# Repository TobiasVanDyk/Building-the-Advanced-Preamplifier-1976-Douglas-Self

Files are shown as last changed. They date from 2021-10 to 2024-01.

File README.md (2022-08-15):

**Copyright 1976 November Wireless World An Advanced Preamplifier** by [**Douglas Self**](http://www.douglas-self.com/ampins/library/ampartew.htm)

Douglas Self's audio design books are also recommended on Github: [**How to learn modern electronics**](https://github.com/joaocarvalhoopen/How_to_learn_modern_electronics)

This is the most musically sounding preamp I have built. The photograph shows the two normalization and tone control PCB's constructed in the middle 1980's, re-housed in a recent (partially) 3d-printed, case. The input level control is at the back of the case. 

<p align="left">
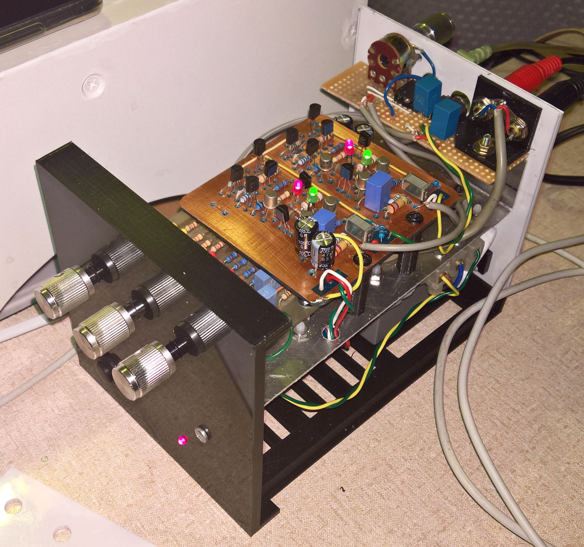
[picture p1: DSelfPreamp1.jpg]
  
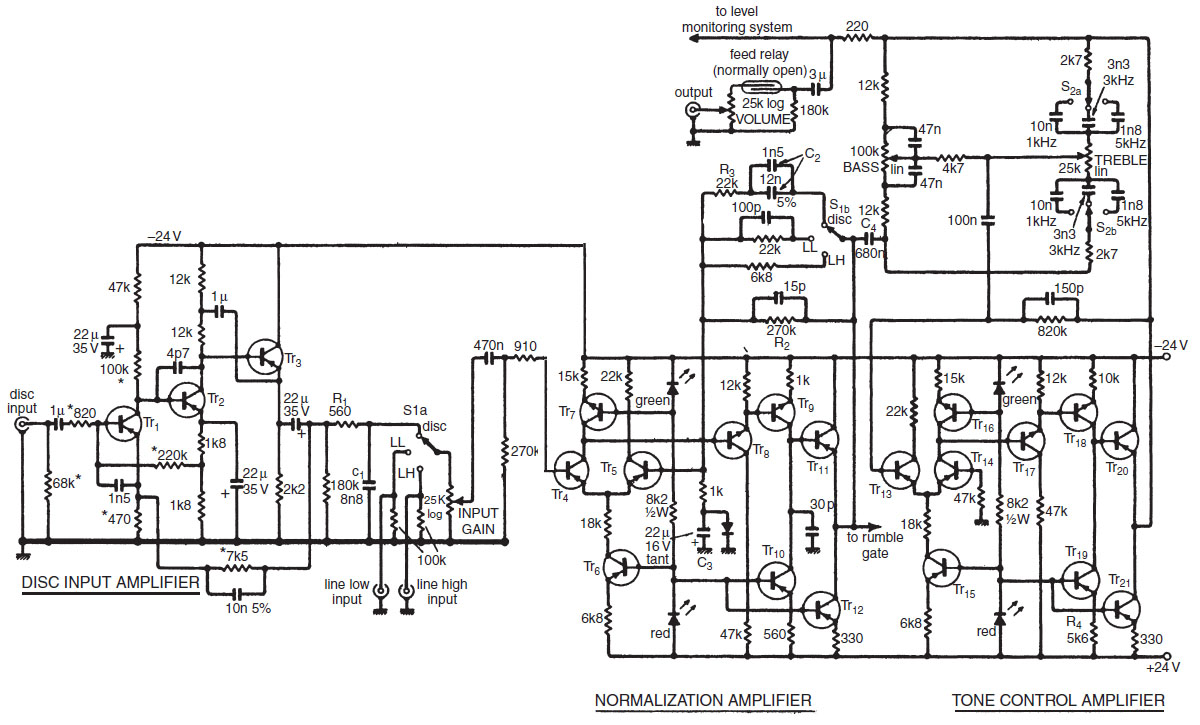
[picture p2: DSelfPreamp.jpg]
   
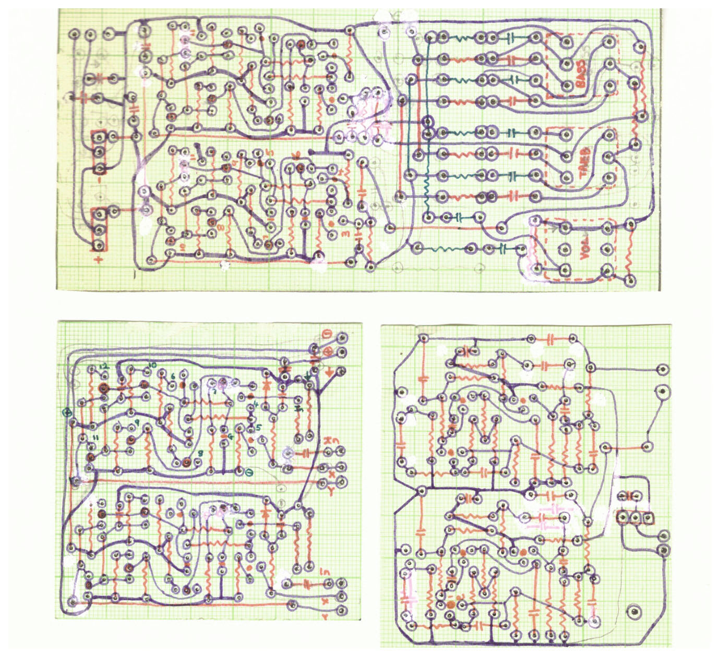
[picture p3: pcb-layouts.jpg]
  	
</p>
	
Listening during the past year (2020/2021) to this preamp driving a linear-PSU-powered class-D-amp prompted the construction of a second preamp - the unpopulated PCBs have been made and the components obtained. More details are in the [AdvPreAmp2021Build](AdvPreAmp2021Build) folder including the Fritzing PCB layout files. (*No, it is not cool to have to create a schematic, if all that you want is a PCB based on a perfectly good schematic that you already have. [Note 1](https://github.com/geedotk/CS42448_T4_TEST2) [Note 2](https://hackaday.io/project/2984-teensy-audio-library/log/187557-updated-cs42448-pcb-for-teensy-4x)*) An old trick that I use to make the PCB photomasks is to laserprint on normal white paper, rub some sunflower oil over the non-toner side, and then let it dry for 24 hours.

<p align="left">
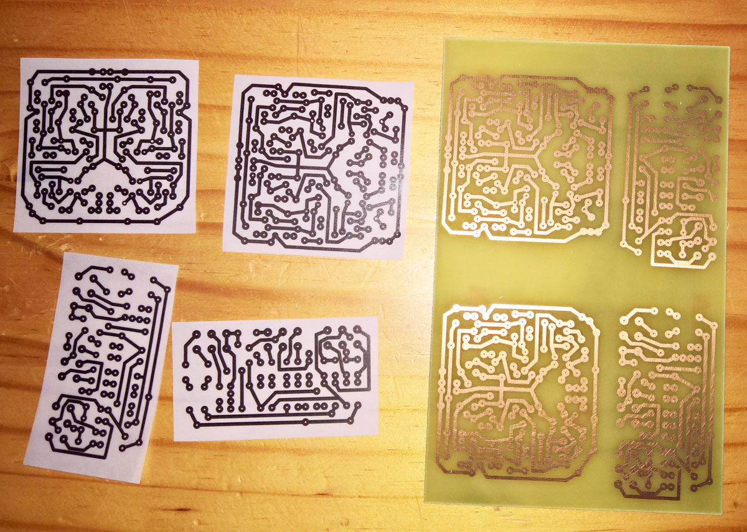
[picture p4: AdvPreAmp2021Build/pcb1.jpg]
  
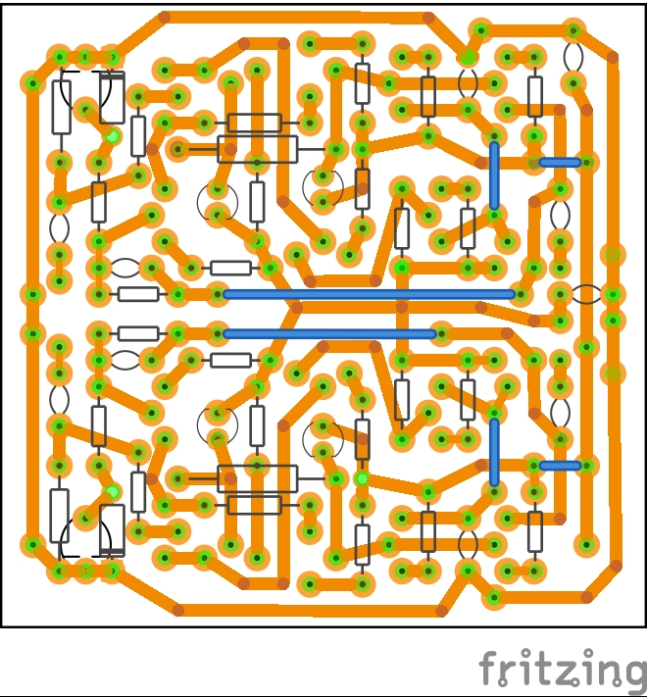
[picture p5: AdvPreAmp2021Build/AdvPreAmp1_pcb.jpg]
   
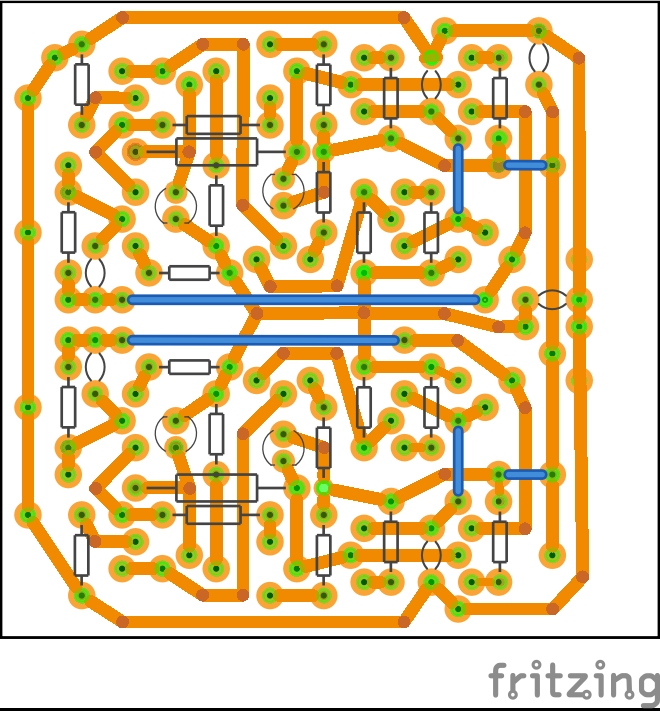
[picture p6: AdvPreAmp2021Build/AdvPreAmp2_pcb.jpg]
  
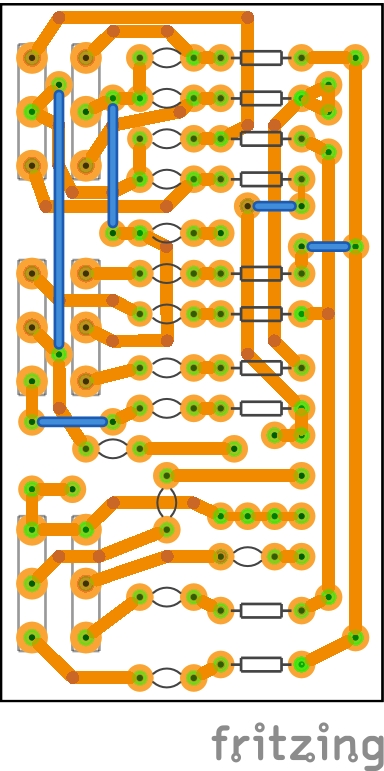
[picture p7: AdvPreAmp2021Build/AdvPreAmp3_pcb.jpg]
  
</p>

The Preamp electronics have been completed - only the case is left to make or print:
<p align="left">
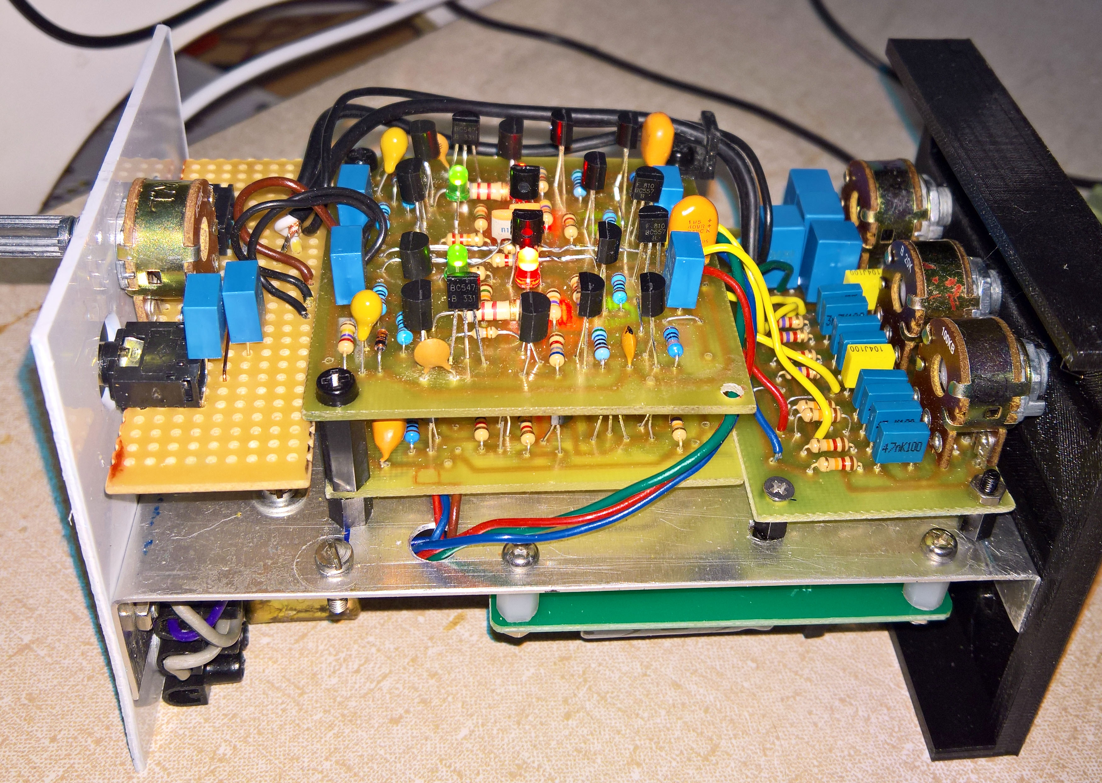
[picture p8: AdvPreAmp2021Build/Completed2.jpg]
  
</p>

This turned out to be almost half the size of the 1980's based preamp, and puzzlingly it has a distinctly different sound (but neither better nor worse), than the older preamp.

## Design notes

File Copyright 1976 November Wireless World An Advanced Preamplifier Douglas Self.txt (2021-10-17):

Copyright 1976 November Wireless World An Advanced Preamplifier Douglas Self

http://www.douglas-self.com/ampins/library/ampartew.htm

This is the most musically sounding preamp I have ever built. The photograph shows the two normalization and tone control PCB's from the middle 1980's re-housed in a recent case.

<p align="left">
  
    
</p>

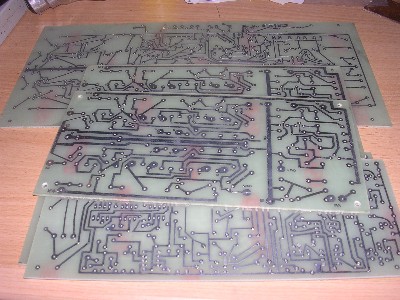
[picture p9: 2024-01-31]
original-pcb.jpg

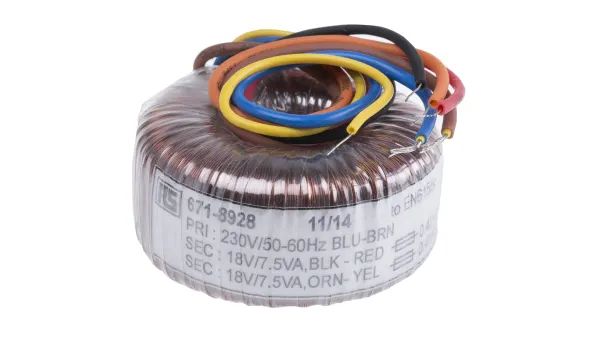
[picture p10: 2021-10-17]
RSPro-671-8928.jpg

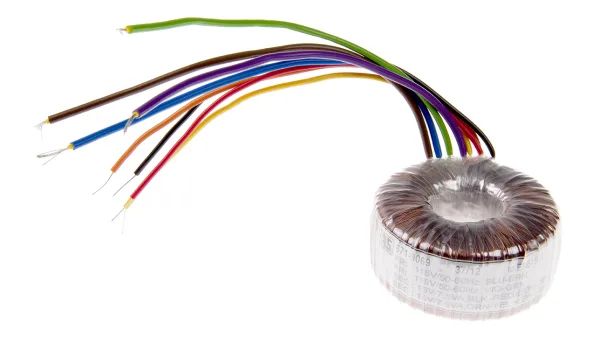
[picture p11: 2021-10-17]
RSPro-671-9069.jpg

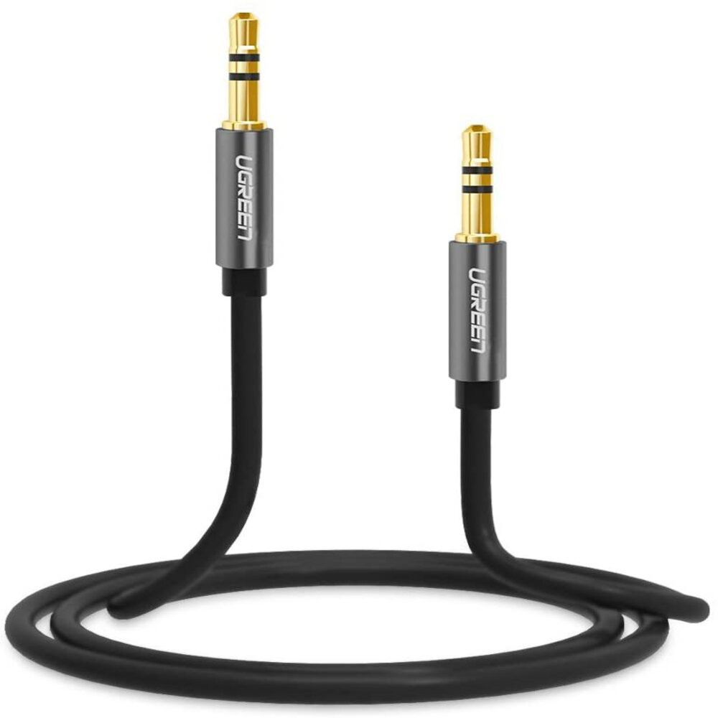
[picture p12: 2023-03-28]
AudioSwitchBox-3Way/UGreen 3mm5 50cm Audio Cable.jpg

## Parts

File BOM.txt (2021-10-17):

BOM: Normalization Amp and Tone Control Amp only
------------------------------------------------
Tr4  5  6  13 14 15  are BCY71  PNP
Tr7  8  9  16 17 18  are MPSA06 NPN
Tr10 11 12 19 20 21  are MPSA56 PNP
MPSA56 x 12
MPSA06 x 12
BCY71 (BC560C) x 12
Note: 
1. MPSA06 and MPSA56 are still manufactured
MPSA56 https://www.mantech.co.za/ProductInfo.aspx?Item=14M6921
MPSA06 https://www.mantech.co.za/ProductInfo.aspx?Item=14M6920
2. BCY71 can be substituted with BC560C
BC560C https://www.mantech.co.za/ProductInfo.aspx?Item=14M0390
3. For Disc Imput Amp add BCY71 (BC560C) x 6 
   And resistors/capacitors as per circuit diagram
--------------------------------------------------------
220 x 2
330 x 4
560 x 2
910 x 2
1k x 8
2k7 x 4
4k7 x 2
5k6 x 2
6k8 x 6
8k2 x 4 1/2 W
10k x 4
12k x 8
15k x 4
18k x 4
22k x 6
47k x 4
100k x 4
180k x 2
270k x 4
820k x 2
-----------------
25k dual log x 2
25k dual lin x 1
100k dual lin x 1
-----------------
15pF x 2
30pF x 2
100pF x 2
150pF x 2
10n x 4
3n3 x 4
1n8 x 4
47n x 4
100n x 2
470n x 2
3uF x 2
22uF 16v electrolytic x 2
--------------------------
PSU:
18-0-18 volt 15VA toroidal transformwr RSPro 671-8928 https://za.rs-online.com/web/p/toroidal-transformers/6718928/ (1985 re-build)
15-0-15 volt 15VA toroidal transformwr RSPro-671-9069 https://za.rs-online.com/web/p/toroidal-transformers/6719069/ (2021 new build)
4700uF 35v x 2 
400v 2A bridge rectifier

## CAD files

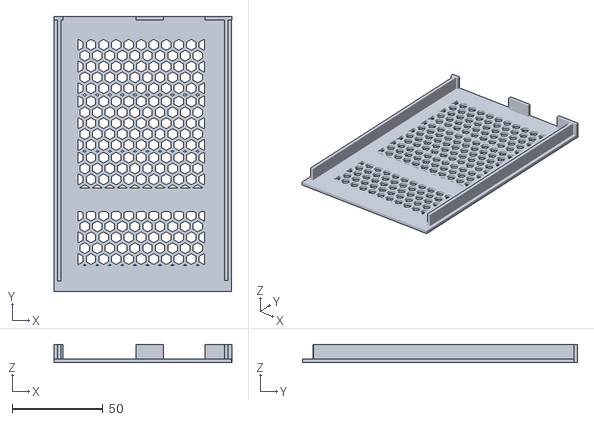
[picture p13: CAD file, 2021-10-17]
1985buildSTL/1985Top.stl
98.3 x 152.0 x 10.0

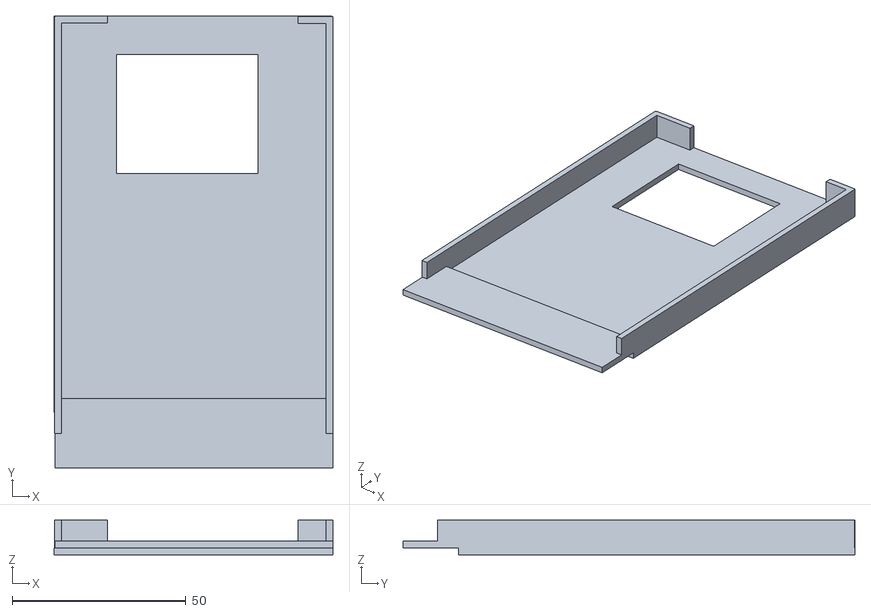
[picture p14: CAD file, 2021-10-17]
AdvPreAmp2021Build/2021buildSTL/2021Bottom.stl
80.3 x 130.2 x 10.0

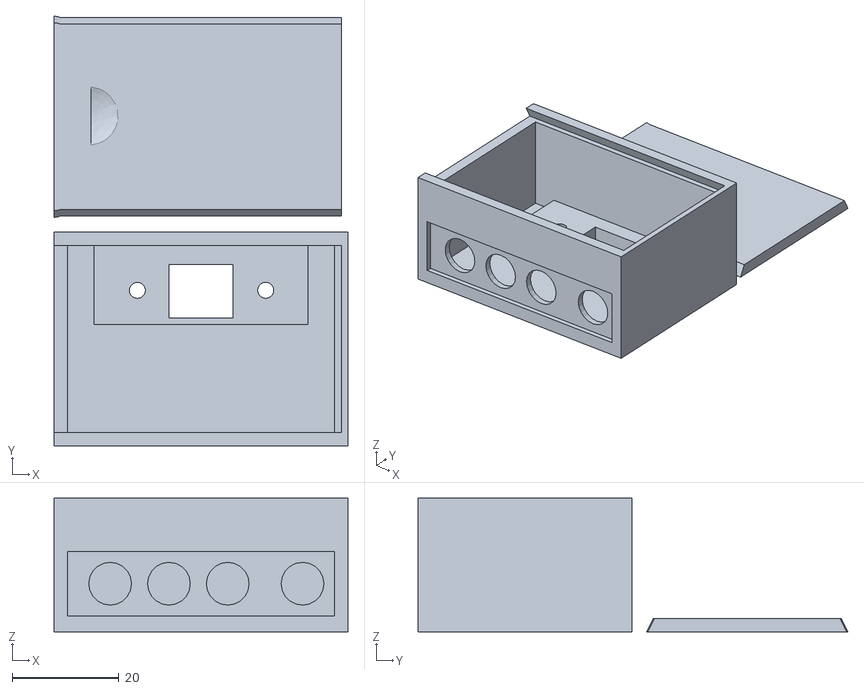
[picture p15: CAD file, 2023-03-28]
AudioSwitchBox-3Way/AudioSwitchBox5.stl
55.0 x 80.4 x 25.0

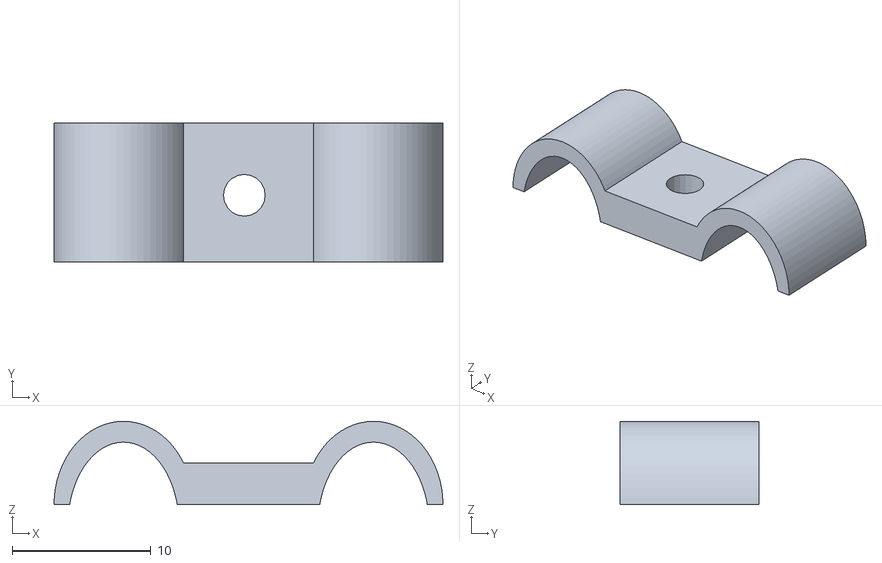
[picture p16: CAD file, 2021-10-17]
1985buildSTL/DoubleClamp.stl
28.0 x 10.0 x 6.00

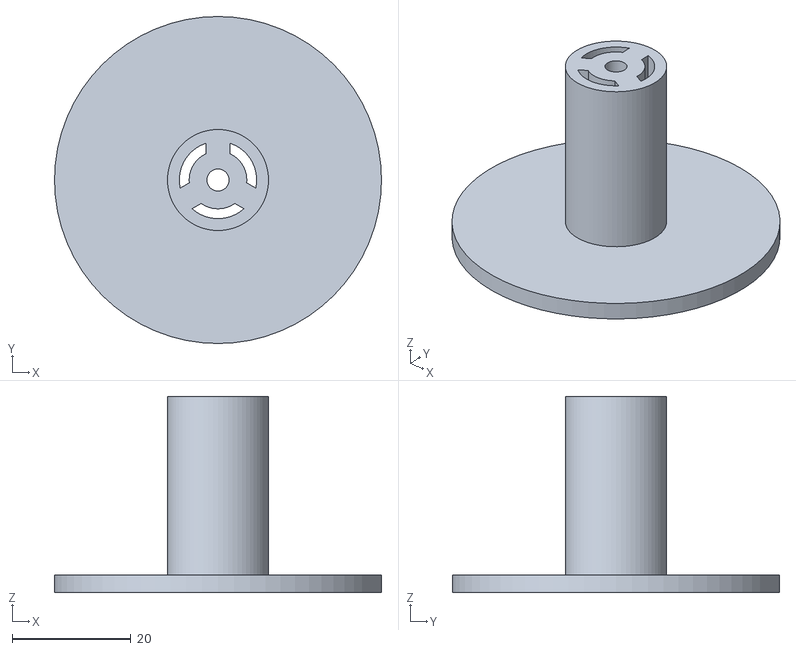
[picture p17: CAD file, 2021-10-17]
AdvPreAmp2021Build/2021buildSTL/Transformer Toroidal 15VA 2x18V.stl
55.0 x 55.0 x 33.0

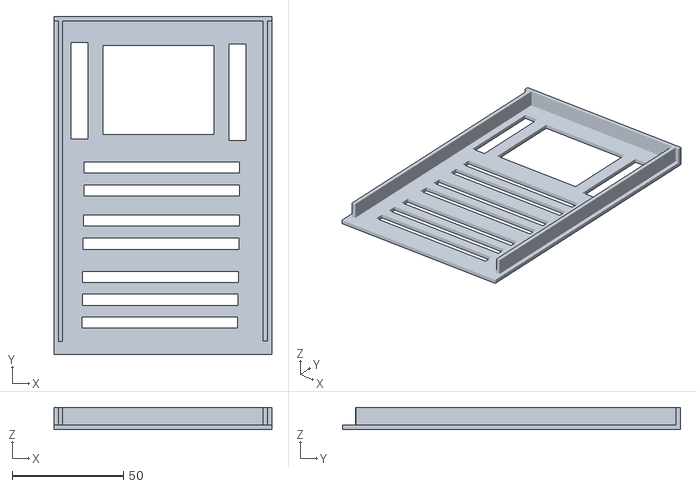
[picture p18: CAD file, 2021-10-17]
1985buildSTL/1985Bottom.stl
98.0 x 152.0 x 10.0

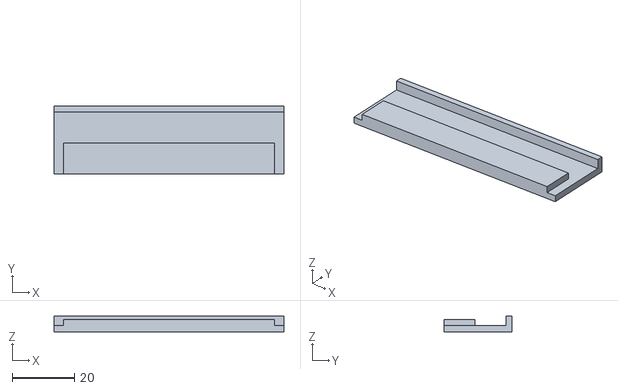
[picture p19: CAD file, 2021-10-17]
AdvPreAmp2021Build/2021buildSTL/2021TopPartB.stl
74.0 x 22.0 x 5.00

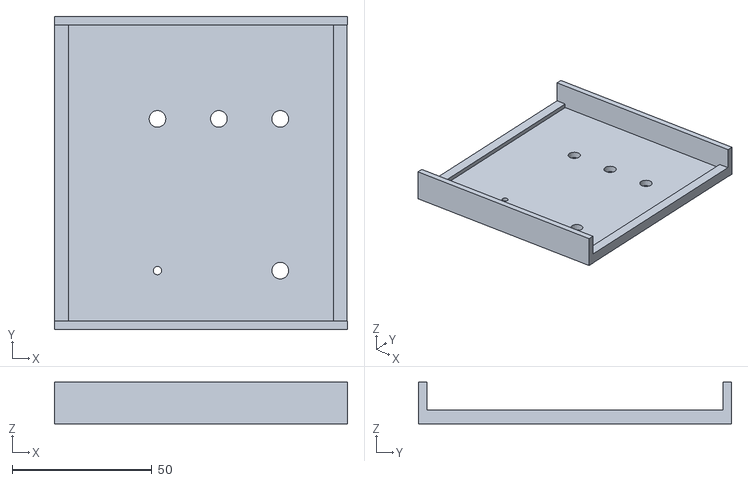
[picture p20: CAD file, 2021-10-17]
1985buildSTL/1985Front.stl
105.0 x 112.2 x 15.0

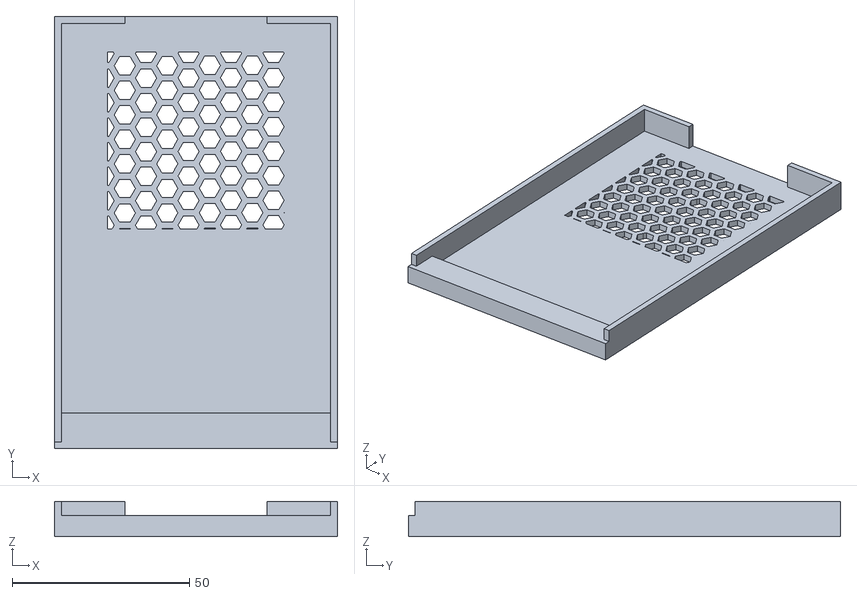
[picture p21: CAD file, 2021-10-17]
AdvPreAmp2021Build/2021buildSTL/2021TopPartA.stl
80.0 x 122.0 x 10.0

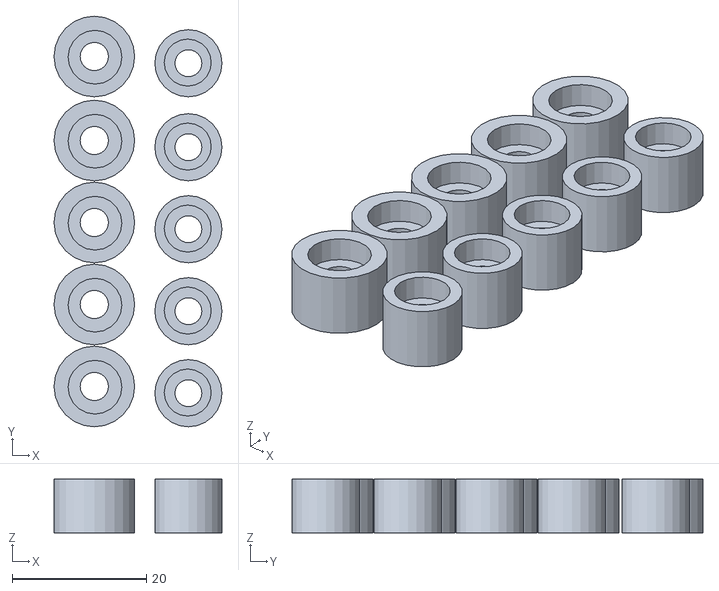
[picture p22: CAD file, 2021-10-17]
AdvPreAmp2021Build/2021buildSTL/2021CaseFeet1.stl
25.0 x 61.1 x 8.00

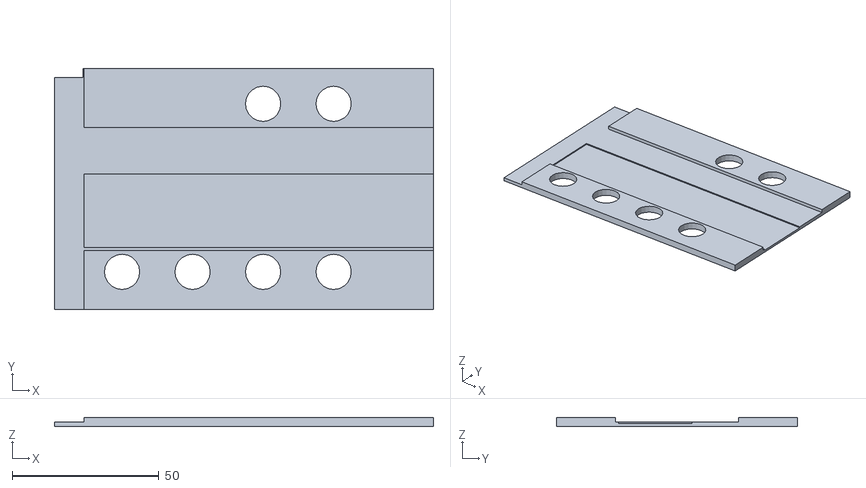
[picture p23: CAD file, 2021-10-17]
AdvPreAmp2021Build/2021buildSTL/PreampSideR.stl
129.0 x 82.0 x 3.00

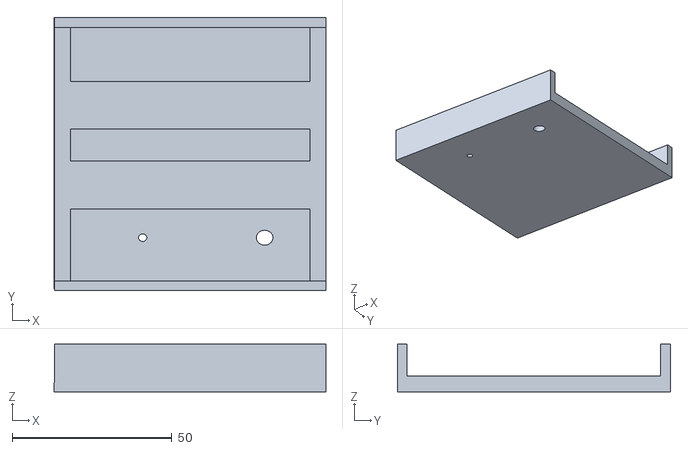
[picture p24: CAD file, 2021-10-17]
AdvPreAmp2021Build/2021buildSTL/2021Front.stl
85.1 x 85.5 x 15.0

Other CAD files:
AdvPreAmp2021Build/2021buildSTL/PreampSideL.stl

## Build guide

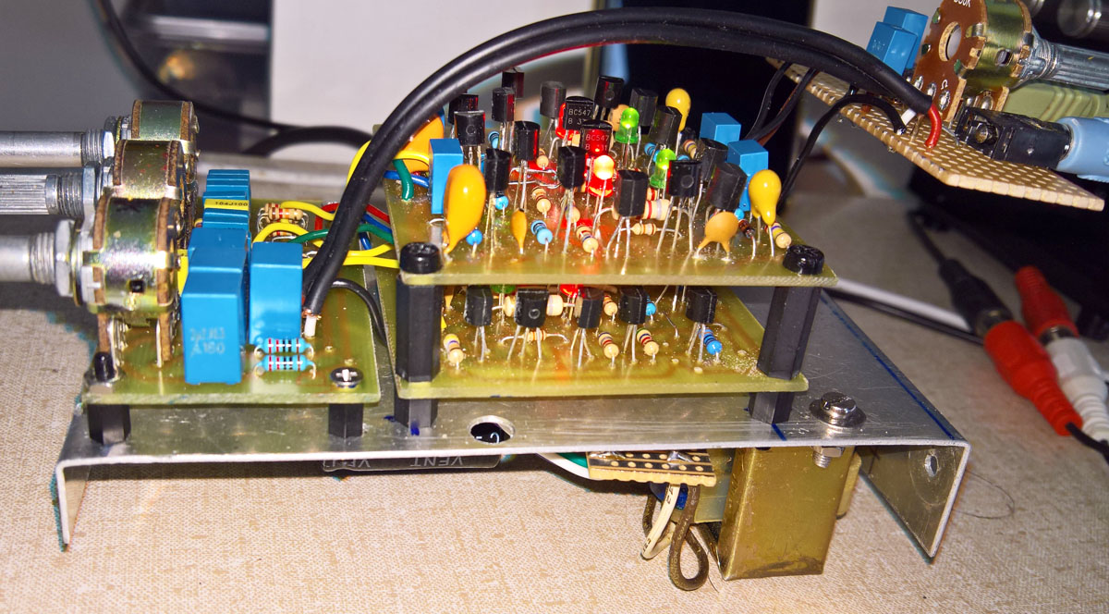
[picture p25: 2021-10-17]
AdvPreAmp2021Build/Completed1.jpg

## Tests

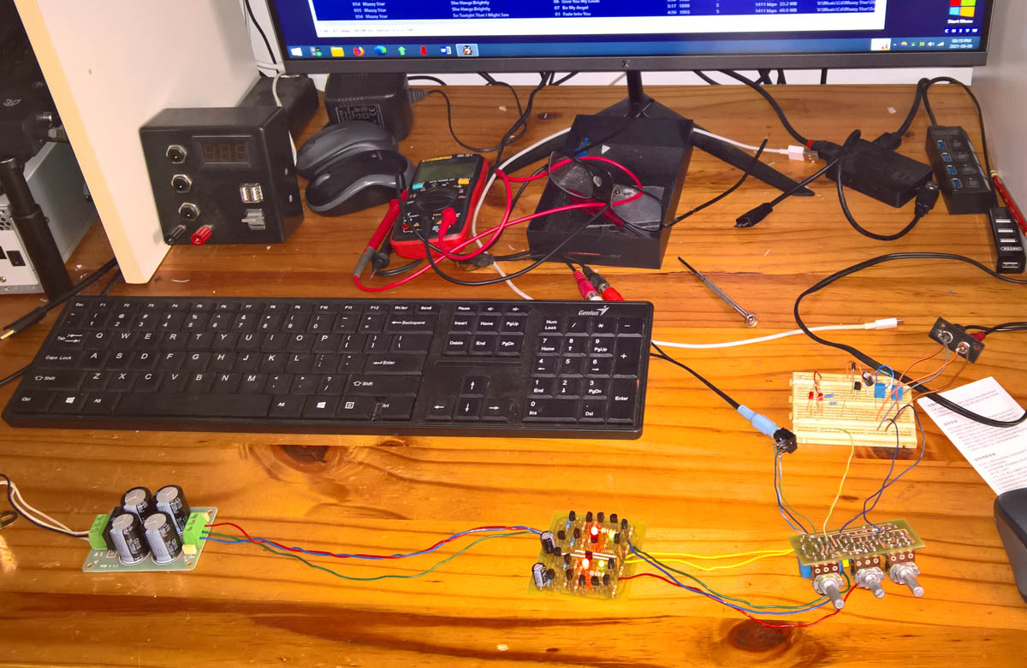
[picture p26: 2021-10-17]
AdvPreAmp2021Build/ToneControlTest.jpg
